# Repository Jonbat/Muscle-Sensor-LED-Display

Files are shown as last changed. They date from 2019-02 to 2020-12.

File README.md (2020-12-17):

<p align="center">
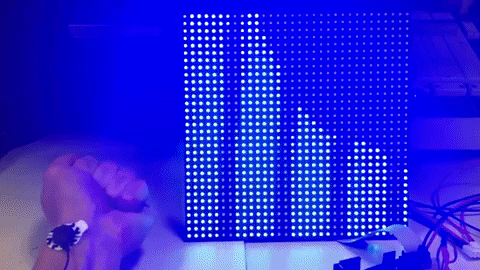
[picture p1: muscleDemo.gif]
 
</p>

## Muscle Sensor LED Display
This micro-controller project measures muscle contractions and displays it on a 32x32 LED screen. The harder you contract your muscle, the larger the wave! Any large enough muscle is compatible, such as the biceps, forearms, or even forehead muscles!
Check out my [youtube video](https://youtu.be/R8VW5WCSrXk) for some step-by-step installation instructions. 👌

## Motivation
Using adafruit's libraries, the slowest processor that can adequately run the [SPX-14633 32x32 matrix](https://sparkfun.com/products/14633) is 16MHz. By avoiding the libraries and driving each pin directly, as this code demonstrates, the LED matrix can adequately be driven on the 1 MHz processor of the atmega164p. 

## Design
The schematic and board files were designed for the Atmega164p and the SPX-14633 32x32 LED screen. Another microcontroller can be used, and this schematic should make a good reference. Because of the fast clock and refresh rate needed to drive the 32x32 LED screen, I would  recommend using a micro controller with a 1 MHz processor and higher. An optional RS-232 serial interface is included for debugging and JTAG interface for on-board programming of the Atmega 164P.

#### Physcial Board
<p align="center">
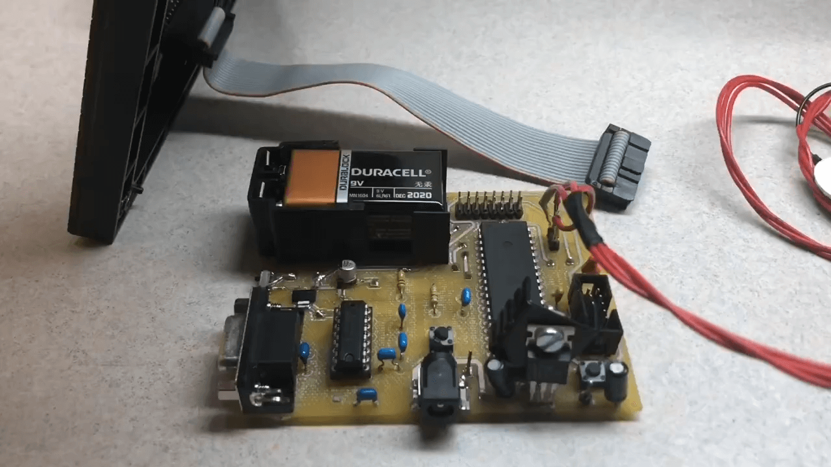
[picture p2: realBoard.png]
 
</p>

#### Schematic
<p align="center">
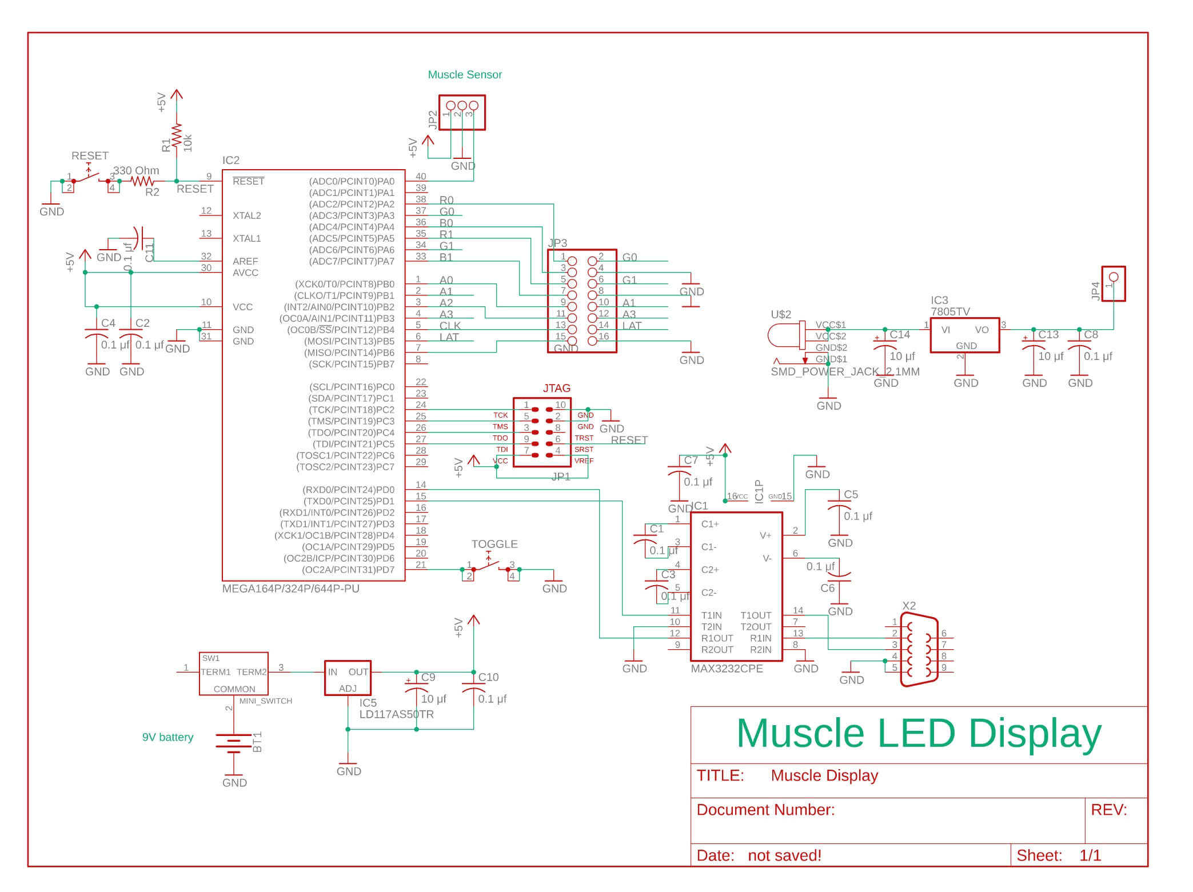
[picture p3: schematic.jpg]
 
</p>

#### Board Design
<p align="center">
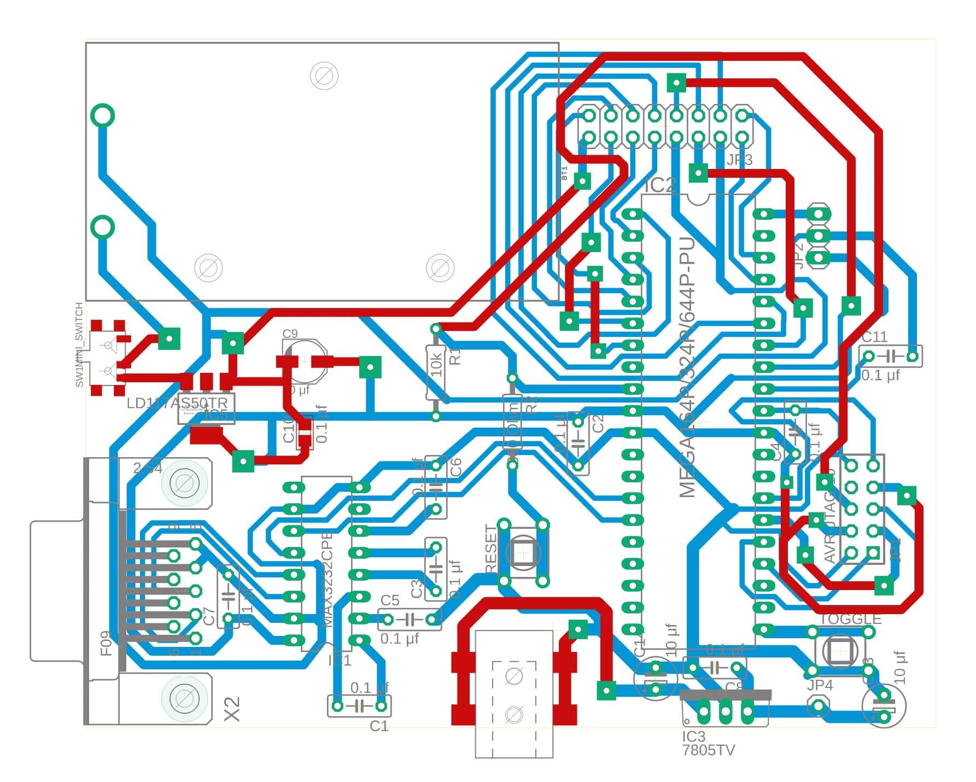
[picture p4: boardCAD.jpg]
 
</p>

## Materials
Muscle Sensor:
* [MyoWare Muscle Sensor  ($37.95)](https://www.adafruit.com/product/2699)
* [Surface EMG Electrodes ($4.95)](https://adafruit.com/product/2773)
* 1x3 Pinhead

Micro-controller:
* [Atmega164p ($3.79)](https://microchip.com/wwwproducts/en/ATmega164P)

LED Panel:
* [32x32 LED Panel- 1:8 scan rate ($14.95)](https://sparkfun.com/products/14633)
* 2x8 pinhead

UART Debugging (optional):
* RS-232 serial interface
* Max232            

On-board Programming (optional):
* Any JTAG programmer to program micro controller
* 2x5 pinhead

Power:
* 7805 voltage regulator
* 9-Volt battery
* Barrel connector

Other (see schematic):
* 2 Buttons
* Several 0.1 μF capacitors
* Several resistors

## Code
The included micro-controller C code does not use any libraries, besides avr/io.

## Installation Help
* [Myoware muscle sensor set-up](https://learn.adafruit.com/getting-started-with-myoware-muscle-sensor)
* [Matrix hook-up guide](https://learn.sparkfun.com/tutorials/rgb-panel-hookup-guide)

## How it works
* [1:8 Scan rate panels](https://www.sparkfun.com/sparkx/blog/2650)

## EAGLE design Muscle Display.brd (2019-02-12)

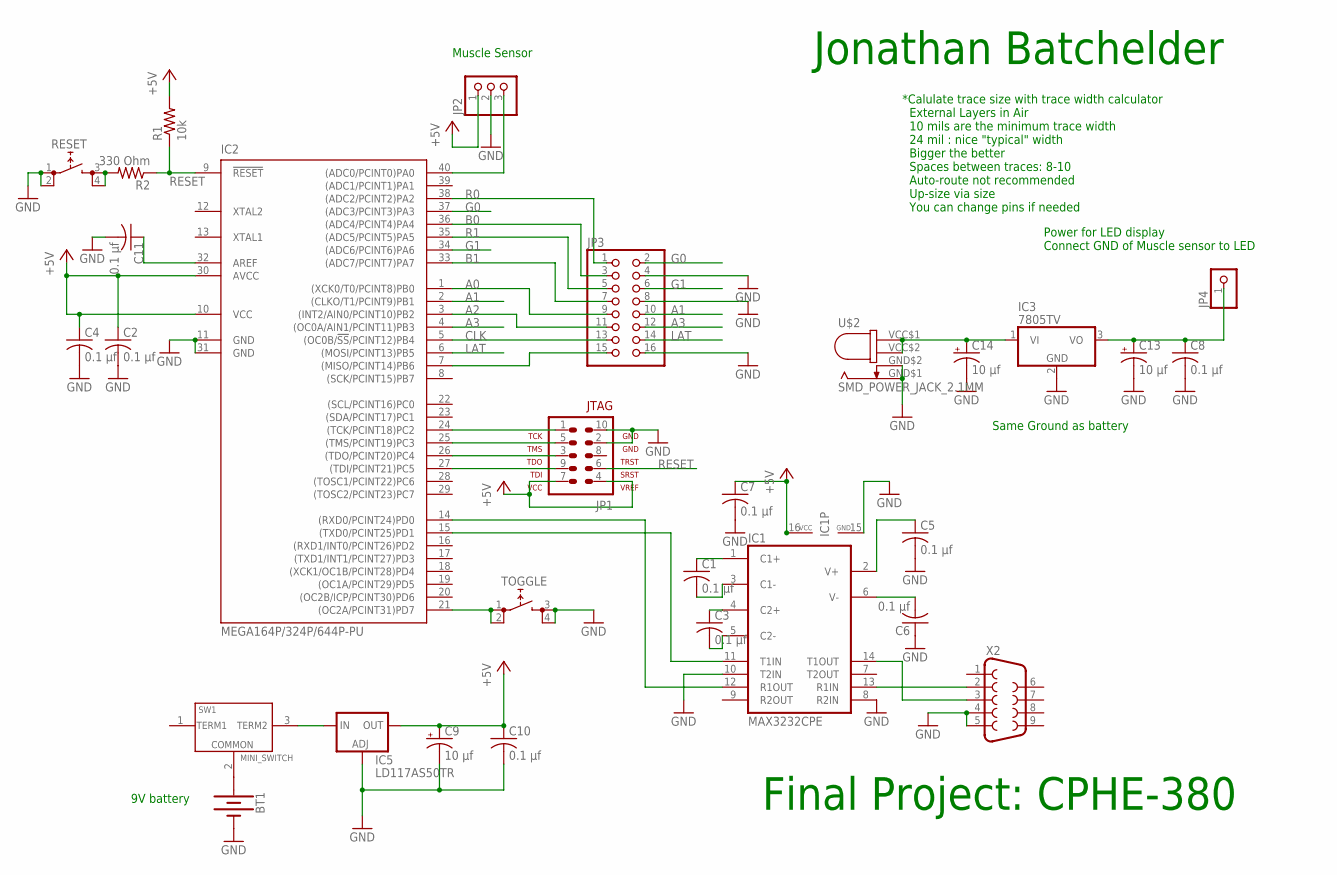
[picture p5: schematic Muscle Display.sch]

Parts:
BT1: BATTERY-9V; BATTCON_9V
C1, C2, C3, C4, C5, C6, C7, C8, C11: 0.1 μf; C050-025X075
C9: 10 μf; PANASONIC_C
C10: 0.1 μf; C0805
C13, C14: 10 μf; E2,5-5
IC1: MAX3232CPE; DIL16
IC2: MEGA164P/324P/644P-PU; DIL40
IC3: 7805TV; TO220V
IC5: LD117AS50TR; SOT223
JP1: AVR-JTAG-10
JP2: PINHD-1X3; 1X03
JP3: PINHD-2X8; 2X08
JP4: PINHD-1X1; 1X01
R1: 10k; 0207/10
R2: 330 Ohm; 0207/10
RESET: PUSHBUTTON; TL1105SP
SW1: MINI_SWITCH
TOGGLE: PUSHBUTTON; TL1105SP
U$2: SMD_POWER_JACK_2.1MM; SMD_POWER-JACK_2.1MM
X2: F09H

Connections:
+5V: C2.1, C4.1, C7.1, C9.+, C10.1, IC1.16 (VCC), IC2.10 (VCC), IC2.30 (AVCC), IC5.4 (OUT), JP1.4, JP1.7, JP2.1, R1.2
A0: IC2.1 ((XCK0/T0/PCINT8)PB0), JP3.9
A1: IC2.2 ((CLKO/T1/PCINT9)PB1), JP3.10
A2: IC2.3 ((INT2/AIN0/PCINT10)PB2), JP3.11
A3: IC2.4 ((OC0A/AIN1/PCINT11)PB3), JP3.12
B0: IC2.36 ((ADC4/PCINT4)PA4), JP3.3
B1: IC2.33 ((ADC7/PCINT7)PA7), JP3.7
CLK: IC2.5 ((OC0B/!SS!/PCINT12)PB4), JP3.13
G0: IC2.37 ((ADC3/PCINT3)PA3), JP3.2
G1: IC2.34 ((ADC6/PCINT6)PA6), JP3.6
GND: BT1.-, C2.2, C4.2, C5.2, C6.1, C7.2, C8.2, C9.-, C10.2, C11.2, C13.-, C14.-, IC1.8 (R2IN), IC1.10 (T2IN), IC1.15 (GND), IC2.11 (GND), IC2.31 (GND), IC3.2 (GND), IC5.1 (ADJ), JP1.2, JP1.10, JP2.2, JP3.4, JP3.8, JP3.16, RESET.1 (0), RESET.2 (0), TOGGLE.3 (1), TOGGLE.4 (1), U$2.GND$1 (OUTSIDE$1), U$2.GND$2 (OUTSIDE$2), X2.4, X2.5
LAT: IC2.6 ((MOSI/PCINT13)PB5), JP3.14
unnamed: C1.1, IC1.1 (C1+)
unnamed: C3.2, IC1.5 (C2-)
unnamed: C3.1, IC1.4 (C2+)
unnamed: IC1.13 (R1IN), X2.2
unnamed: BT1.+, SW1.2 (COMMON)
unnamed: IC5.3 (IN), SW1.3 (IO3)
unnamed: R2.2, RESET.3 (1), RESET.4 (1)
unnamed: IC2.24 ((TCK/PCINT18)PC2), JP1.1
unnamed: IC2.25 ((TMS/PCINT19)PC3), JP1.5
unnamed: IC2.26 ((TDO/PCINT20)PC4), JP1.3
unnamed: IC2.27 ((TDI/PCINT21)PC5), JP1.9
unnamed: IC2.21 ((OC2A/PCINT31)PD7), TOGGLE.1 (0), TOGGLE.2 (0)
unnamed: IC1.14 (T1OUT), X2.3
unnamed: C1.2, IC1.3 (C1-)
unnamed: C8.1, C13.+, IC3.3 (VO), JP4.1
unnamed: C5.1, IC1.2 (V+)
unnamed: C6.2, IC1.6 (V-)
unnamed: C14.+, IC3.1 (VI), U$2.VCC$1 (INSIDE$1), U$2.VCC$2 (INSIDE$2)
unnamed: IC1.12 (R1OUT), IC2.14 ((RXD0/PCINT24)PD0)
unnamed: IC1.11 (T1IN), IC2.15 ((TXD0/PCINT25)PD1)
unnamed: C11.1, IC2.32 (AREF)
OE: IC2.7 ((MISO/PCINT14)PB6), JP3.15
R0: IC2.38 ((ADC2/PCINT2)PA2), JP3.1
R1: IC2.35 ((ADC5/PCINT5)PA5), JP3.5
RESET: IC2.9 (!RESET), JP1.6, R1.1, R2.1
SENSOR_INPUT: IC2.40 ((ADC0/PCINT0)PA0), JP2.3

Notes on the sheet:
Final Project: CPHE-380
Muscle Sensor
9V battery
Jonathan Batchelder
*Calulate trace size with trace width calculator External Layers in Air 10 mils are the minimum trace width 24 mil : nice "typical" width Bigger the better Spaces between traces: 8-10 Auto-route not recommended Up-size via size You can change pins if needed
Power for LED display Connect GND of Muscle sensor to LED
Same Ground as battery

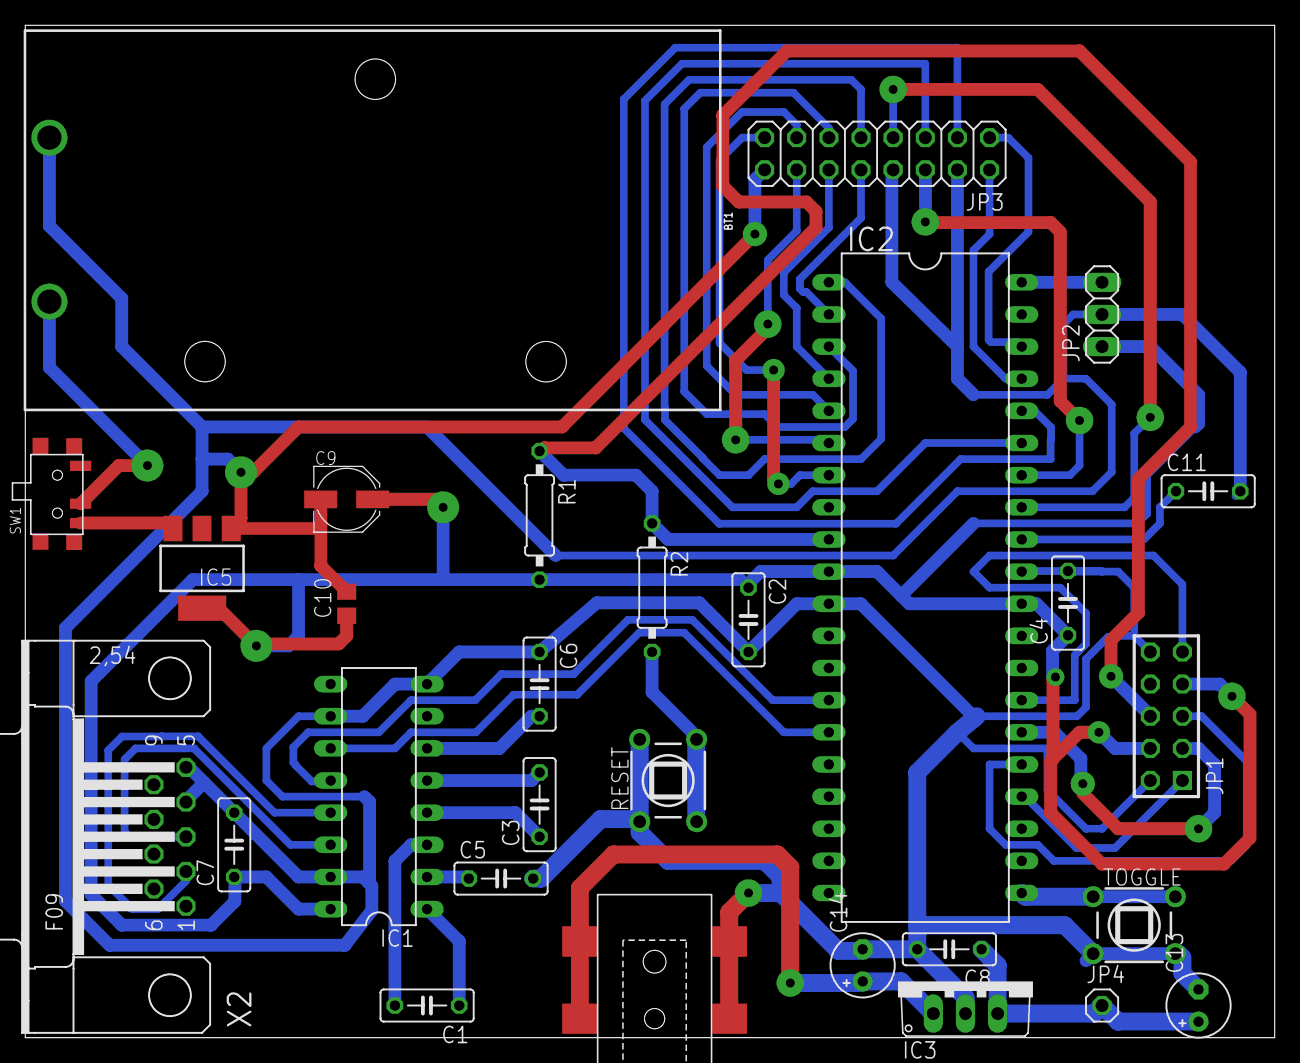
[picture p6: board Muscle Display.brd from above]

Board: 2 copper layers, 98.7 x 80.0 mm, 29 parts (0 on the bottom side), 38 nets.

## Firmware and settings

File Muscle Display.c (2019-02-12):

/*
 * Muscle Sensor.c
 *
 * Created: 12/6/2018 10:24:02 AM
 * Author : Jonathan Batchelder
 */ 

#include <avr/io.h>
#include <util/delay.h>

#define DATAPORT PORTA
#define CLK PB4
#define OE  PB6
#define LAT PB5
#define A  PB0
#define B  PB1
#define C  PB2

#define R1 PA2
#define R2 PA5
#define G1 PA3
#define G2 PA6 
#define B1 PA4
#define B2 PA7

void matrix_init () {
	DDRA = 0xFC;  		// all bits outputs, except PA0 (sensor) and PA1 (unused)
	DDRB = 0xFF;
	PORTA = (1 << PA0);	// pull-up resistor
}

void ADC_init () {
	ADCSRA = (1 << ADEN);    				// enable ADC
	ADCSRA |= (1 << ADATE) | (1 << ADSC);   // start conversation
	ADMUX = (1 << REFS0);
}

uint16_t ReadADC() {
	uint8_t LS_data = ADCL; 
	uint8_t MS_data = ADCH;
	uint16_t adc_data = (MS_data << 8) | LS_data;
	return adc_data;
}


int main(void) {
	uint8_t C1 = B1;		// blue on default
	uint8_t C2 = B2;
	uint8_t addramask = ~(1 << A);
	uint8_t addrbmask = ~(1 << B);
	uint8_t addrcmask = ~(1 << C);
	matrix_init();
	ADC_init();
	
	uint16_t wave_multiplier;
	uint8_t row = 8;				   		// keep track of which row
	
	while (1) {
		uint16_t wave_val = ReadADC() / 2;	// currently configured for 0 - 1696
		for (int row_line = 8; row_line > 0; row_line--) {

			for (int i = 63; i > -1; i--) { // Display needed to be flipped: for (int i = 0; i < 64; i++) 

				DATAPORT &= ~(1 << C1);
				DATAPORT &= ~(1 << C2);
				 
				//  1010 (Display Algorithm)
				if (i >= 16 && i <= 47) {    // 1000
					if ( wave_val > ( (i - 16) * row_line ) ) {
						DATAPORT |= (1 << C2);
					} 					     // 0010
					if ( wave_val > ( (i - 16) * (row_line + 18) ) ) {
						DATAPORT |= (1 << C1);
					}
				}
				// 0101
				else {
					if ( i > 47 ) {
						wave_multiplier = i - 32;
					} else {
						wave_multiplier = i;
					}						// 0100
					if ( wave_val > (wave_multiplier * (row_line + 8)) ) {
						DATAPORT |= (1 << C2);
					}						// 0001
					if ( wave_val > ( wave_multiplier * (row_line + 24)) ) {
						DATAPORT |= (1 << C1);
					}
				}
				PORTB &= ~(1 << CLK); // tick, clock lo
				PORTB |= (1 << CLK);  // tock, clock hi
			}
			// Update row
			if (++row >= 8) {		  // reset row to 0 every 8 times
				row = 0;
			}
			
			PORTB |= (1 << OE);		 // disable output when loading
			PORTB |= (1 << LAT);     // latch data loaded
			
			// next row
			if(row & 0x1)   PORTB |= (1 << A);
			else          	PORTB &= addramask;   
			if(row & 0x2)   PORTB |= (1 << B);
			else            PORTB &= addrbmask;
			if(row & 0x4)   PORTB |= (1 << C);
			else            PORTB &= addrcmask;
			
			PORTB &= ~(1 << OE);	// output enabled
			PORTB &= ~(1 << LAT);	// latch down, ready for more
		}
	}
}

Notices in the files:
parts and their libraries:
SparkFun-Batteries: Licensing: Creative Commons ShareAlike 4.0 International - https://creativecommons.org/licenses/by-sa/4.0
